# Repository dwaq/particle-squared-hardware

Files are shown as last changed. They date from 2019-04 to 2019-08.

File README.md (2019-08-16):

# Particle Squared - Bare Bones

This is a forked version of [Jared Wolff's Particle Squared Hardware](https://bitbucket.org/circuitdojo/particle-squared-hardware). For more information on that board, [visit his website](https://www.jaredwolff.com/particle-squared-air-quality-sensor/). To support him and his work, you can  [order his sensors from here](https://www.jaredwolff.com/store/particle-squared/).

Particle^2 (pronounced Particle Squared) is a circuit board that helps you monitor the air quality around you. I call my fork of the project "Bare Bones" because I removed the air particulate sensor. It can still monitor humidity, temperature, eCO2 and TVOCs.

I also made some minor changes to the project to suit my goals.

This project was designed using Autodesk Eagle.

The [Eagle-Renders](/Eagle-Renders) directory contains PDF and PNG renders of the schematic and board layout.

[Here is a shared project on Mouser for the BOM for one PCB.](https://www.mouser.com/ProjectManager/ProjectDetail.aspx?AccessID=5dd38de383)

## License

The license for these files is: [Attribution-ShareAlike 4.0 International](https://creativecommons.org/licenses/by-sa/4.0/). See included `LICENSE` file for all the legal stuff.

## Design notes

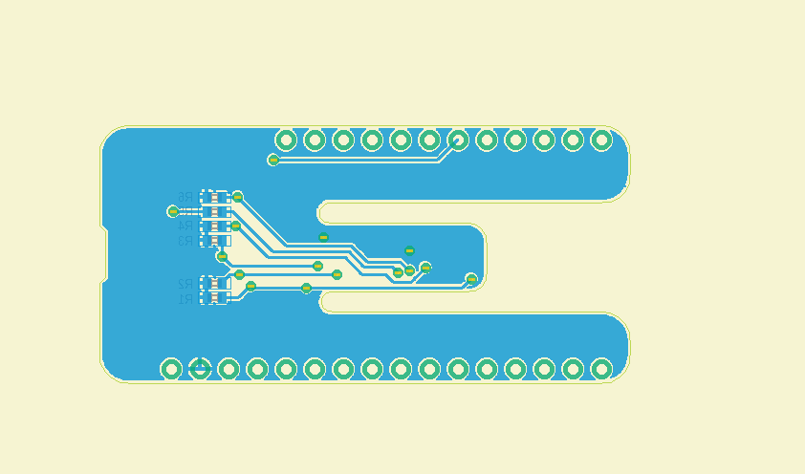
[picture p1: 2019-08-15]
Eagle-Renders/pm25.bot.brd.png

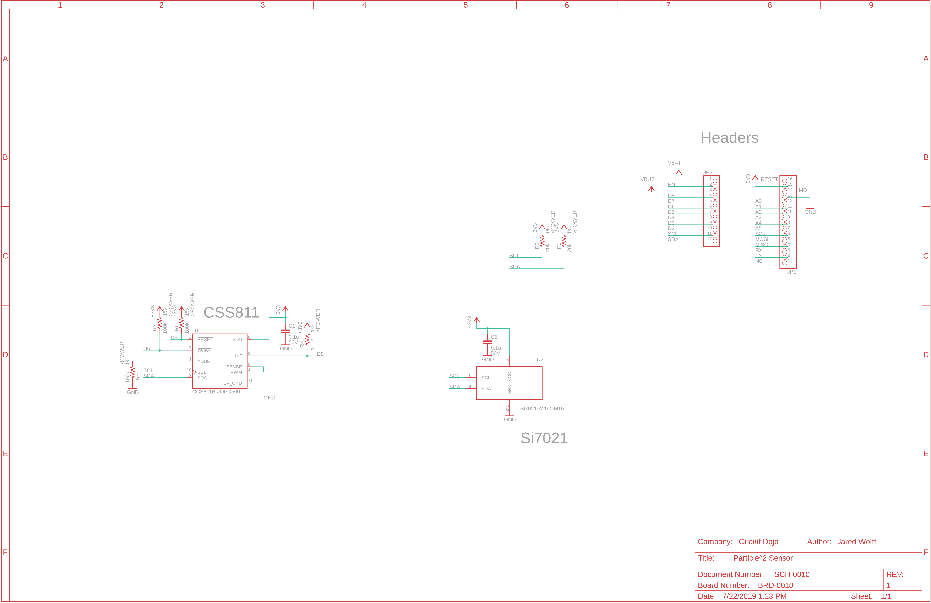
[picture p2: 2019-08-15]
Eagle-Renders/pm25.sch.png

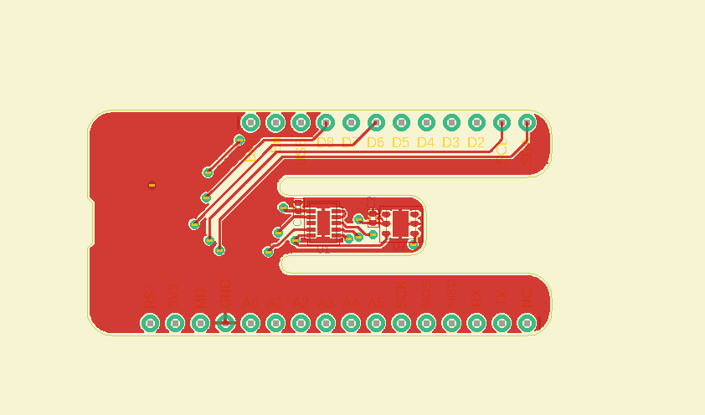
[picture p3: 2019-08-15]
Eagle-Renders/pm25.top.brd.png

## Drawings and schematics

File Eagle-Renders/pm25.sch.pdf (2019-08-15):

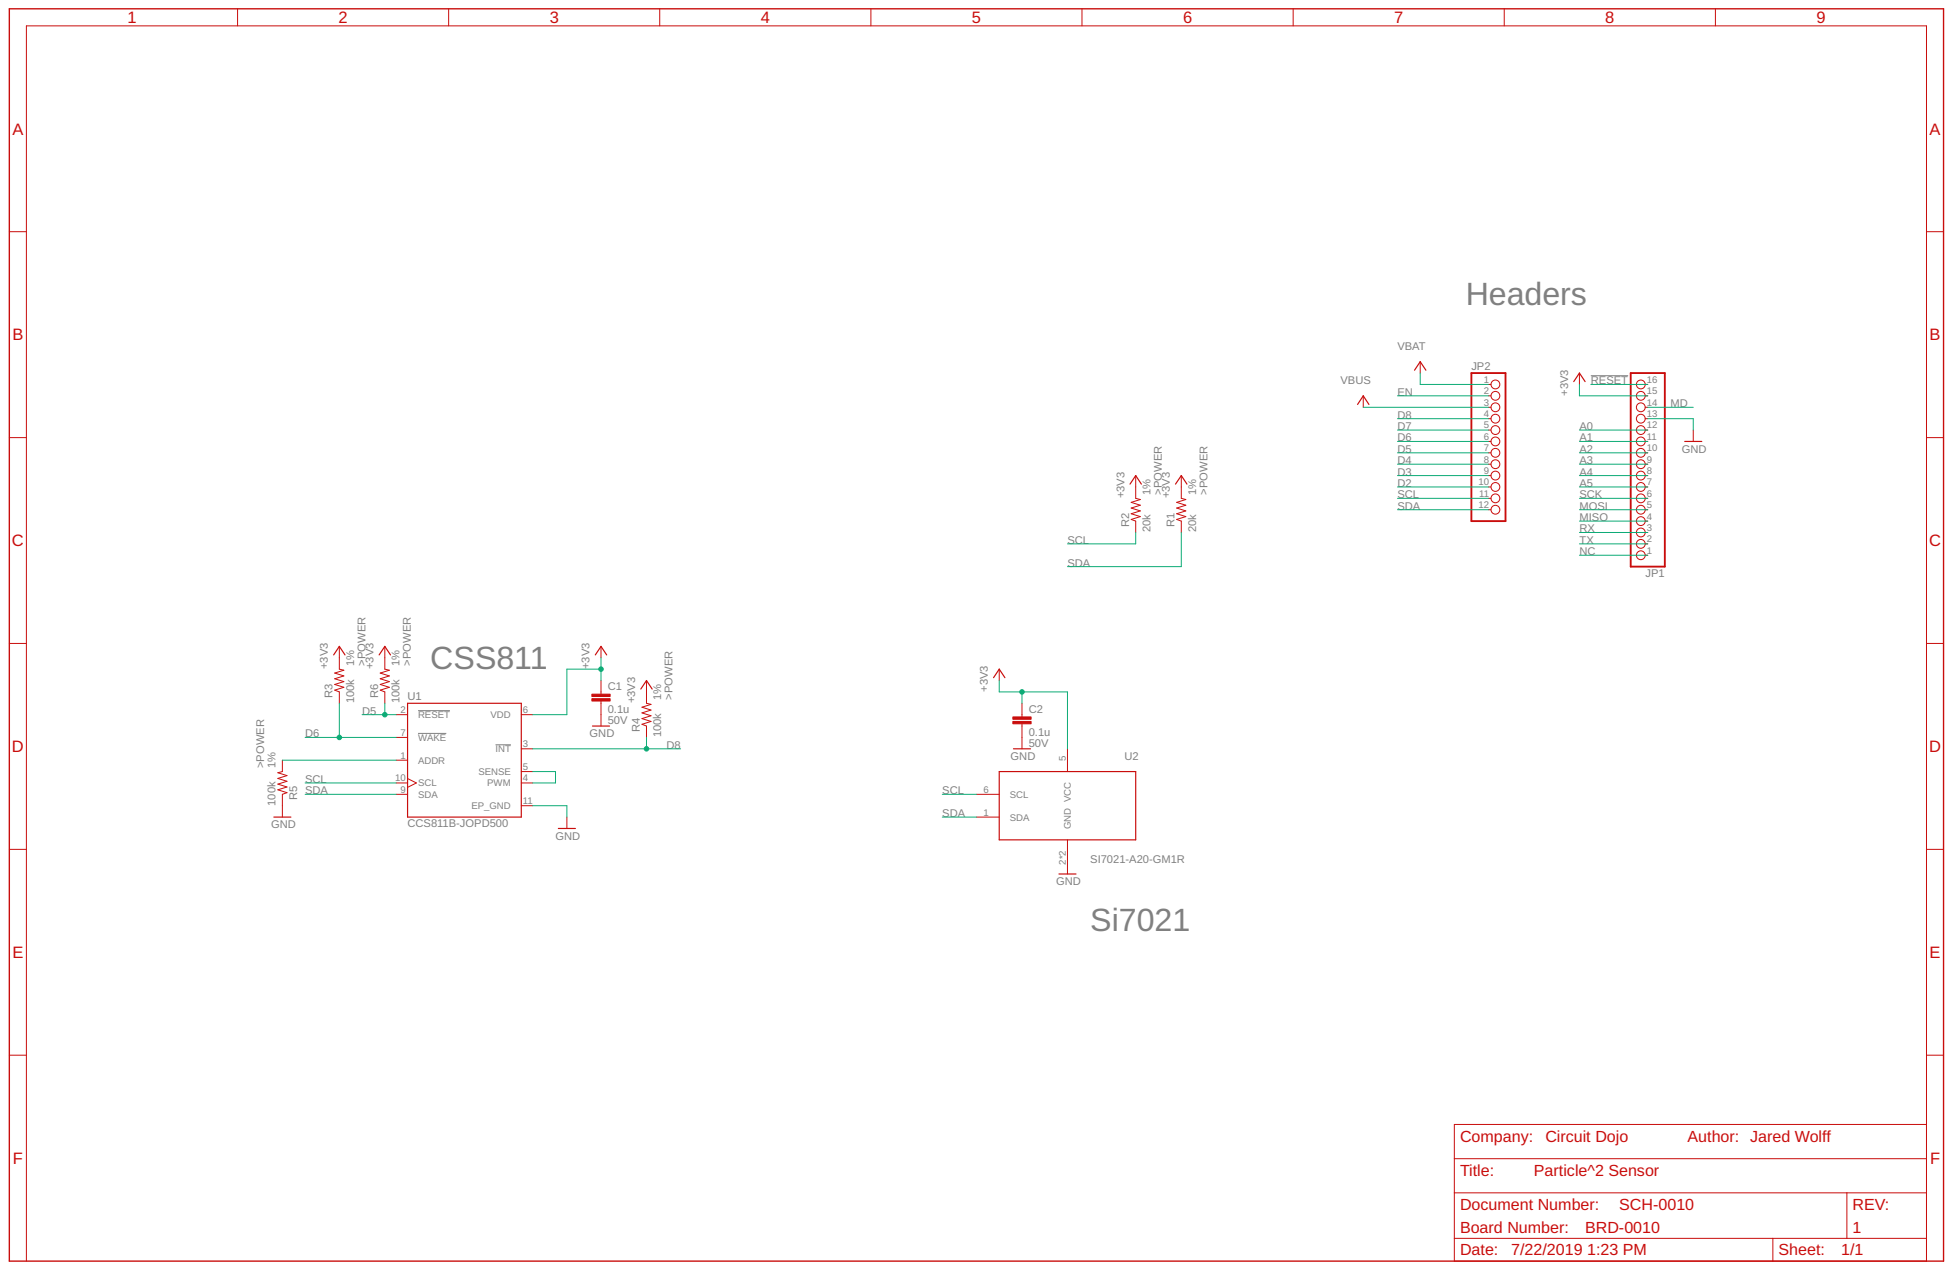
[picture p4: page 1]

Document Number: SCH-0010 Board Number: BRD-0010 | REV: 1

Date: 7/22/2019 1:23 PM | Sheet: 1/1

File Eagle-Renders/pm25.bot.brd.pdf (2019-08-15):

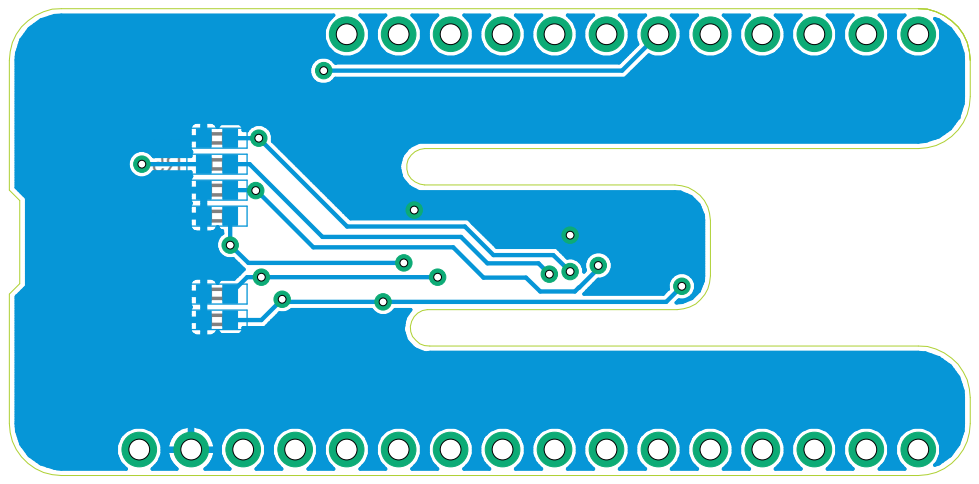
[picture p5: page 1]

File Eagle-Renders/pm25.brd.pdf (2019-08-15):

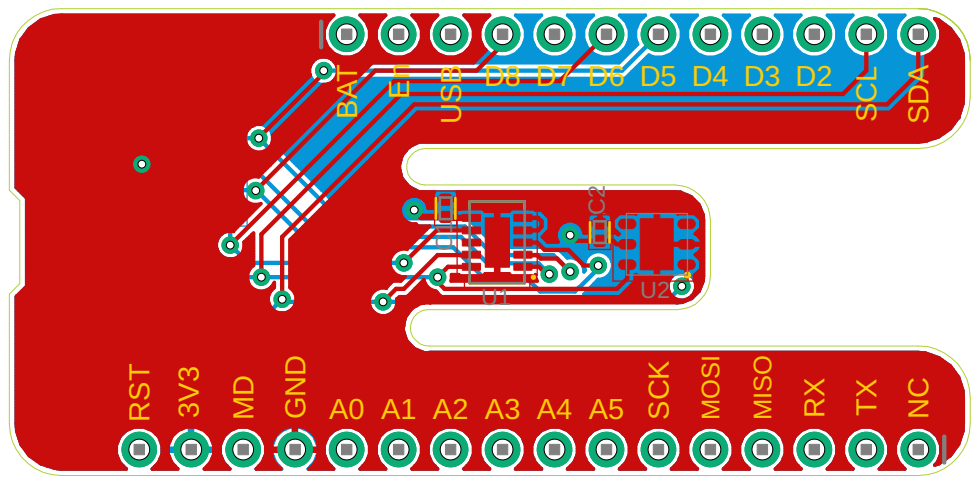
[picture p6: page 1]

6 R3 R4 R5 R2 R1 R USB SCL SDA BATEn RST MD3V3 A0 A1 A2 A3 A4 A5 SCK MOSI MISO RXTXGND NC D8 D7 D6 D5 D4 D3 D2 U1 U2 C1 C2

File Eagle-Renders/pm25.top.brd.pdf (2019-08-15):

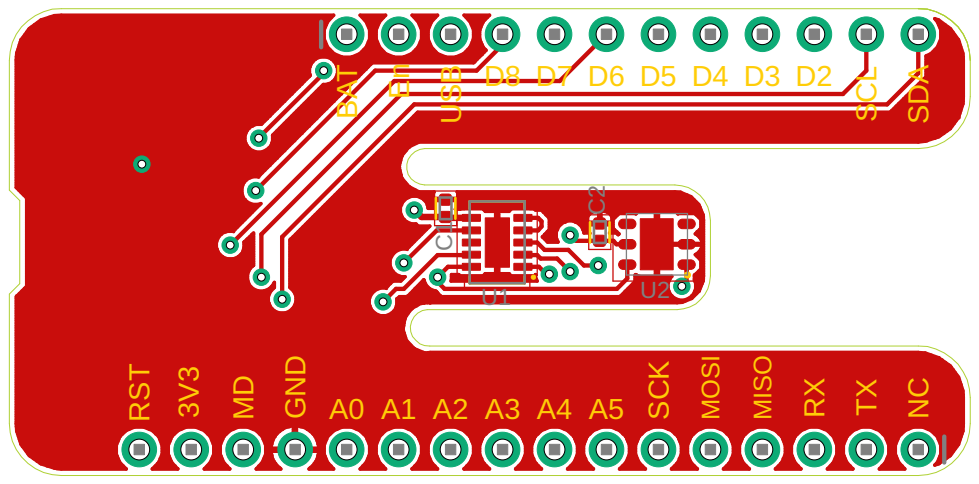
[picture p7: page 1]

3V3 A0 A1 A2 A3 A4 A5 SCK MOSI MISO RX

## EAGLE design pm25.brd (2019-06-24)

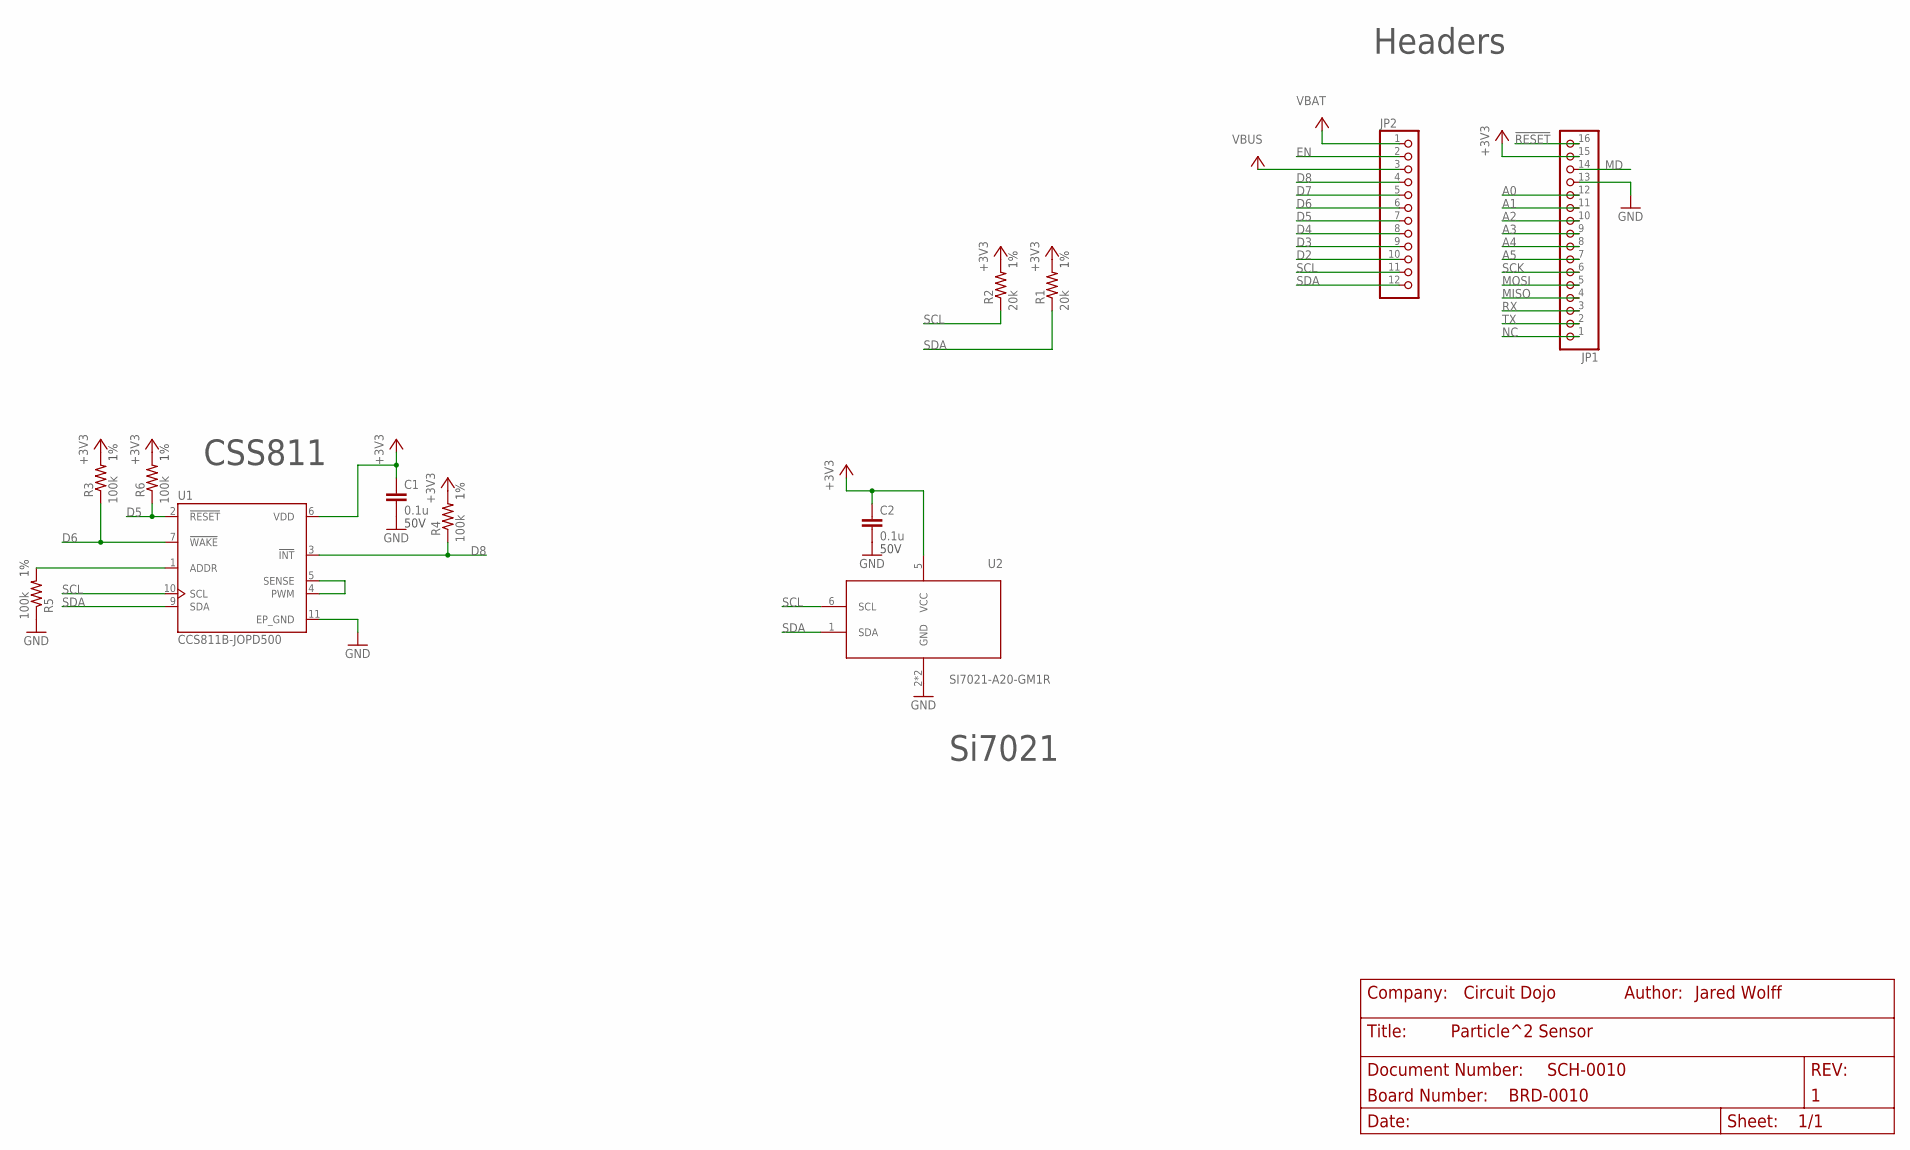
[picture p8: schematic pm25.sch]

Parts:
C1, C2: 0.1u; CAPC1005X55N
JP1: HEADER-1X16ROUND; 1X16_ROUND; MPN PPPC161LFBN-RC
JP2: HEADER-1X12; 1X12_ROUND; MPN PPPC121LFBN-RC
R1, R2: 20k; R0402
R3, R4, R5, R6: 100k; R0402
U1: CCS811B-JOPD500; SON60P400X270X110-11N
U2: SI7021-A20-GM1R; SON100P300X300X80-7N

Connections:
!RESET: JP1.16
+3V3: C1.1, C2.1, JP1.15, R1.2, R2.2, R3.2, R4.2, R6.2, U1.6 (VDD), U2.5 (VCC)
A0: JP1.12
A1: JP1.11
A2: JP1.10
A3: JP1.9
A4: JP1.8
A5: JP1.7
D2: JP2.10
D3: JP2.9
D4: JP2.8
D5: JP2.7, R6.1, U1.2 (!RESET)
D6: JP2.6, R3.1, U1.7 (!WAKE)
D7: JP2.5
D8: JP2.4, R4.1, U1.3 (!INT)
EN: JP2.2
GND: C1.2, C2.2, JP1.13, R5.1, U1.11 (EP_GND), U2.2 (GND), U2.7 (GND)
MD: JP1.14
MISO: JP1.4
MOSI: JP1.5
unnamed: R5.2, U1.1 (ADDR)
unnamed: U1.4 (PWM), U1.5 (SENSE)
NC: JP1.1
RX: JP1.3
SCK: JP1.6
SCL: JP2.11, R2.1, U1.10 (SCL), U2.6 (SCL)
SDA: JP2.12, R1.1, U1.9 (SDA), U2.1 (SDA)
TX: JP1.2
VBAT: JP2.1
VBUS: JP2.3

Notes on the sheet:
Si7021
CSS811
Headers

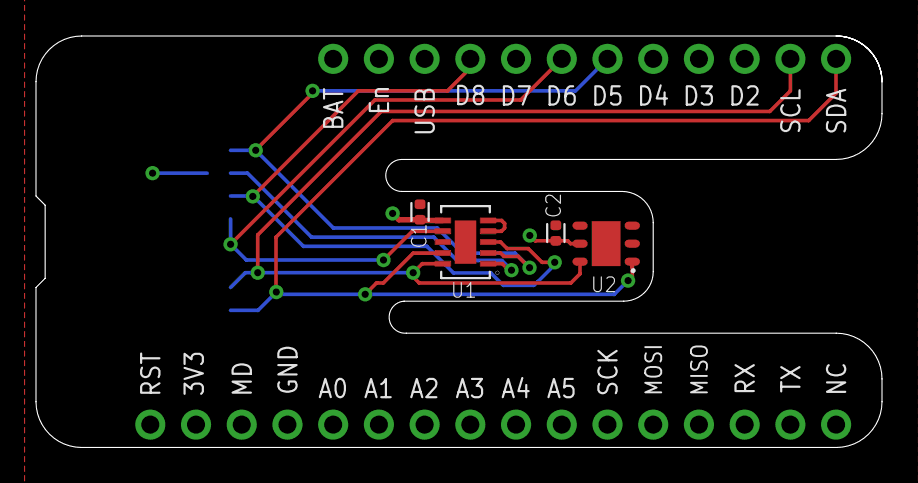
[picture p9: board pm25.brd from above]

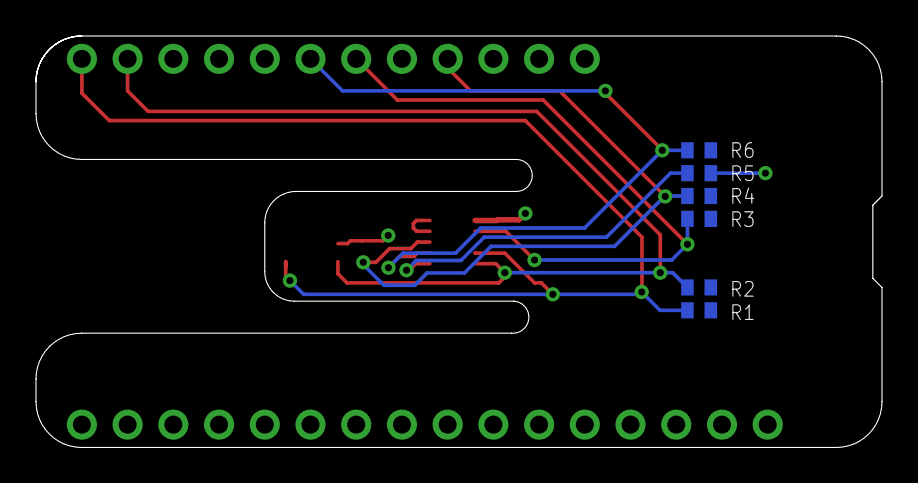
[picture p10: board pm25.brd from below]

Board: 2 copper layers, 47.0 x 22.9 mm, 12 parts (6 on the bottom side), 9 nets.

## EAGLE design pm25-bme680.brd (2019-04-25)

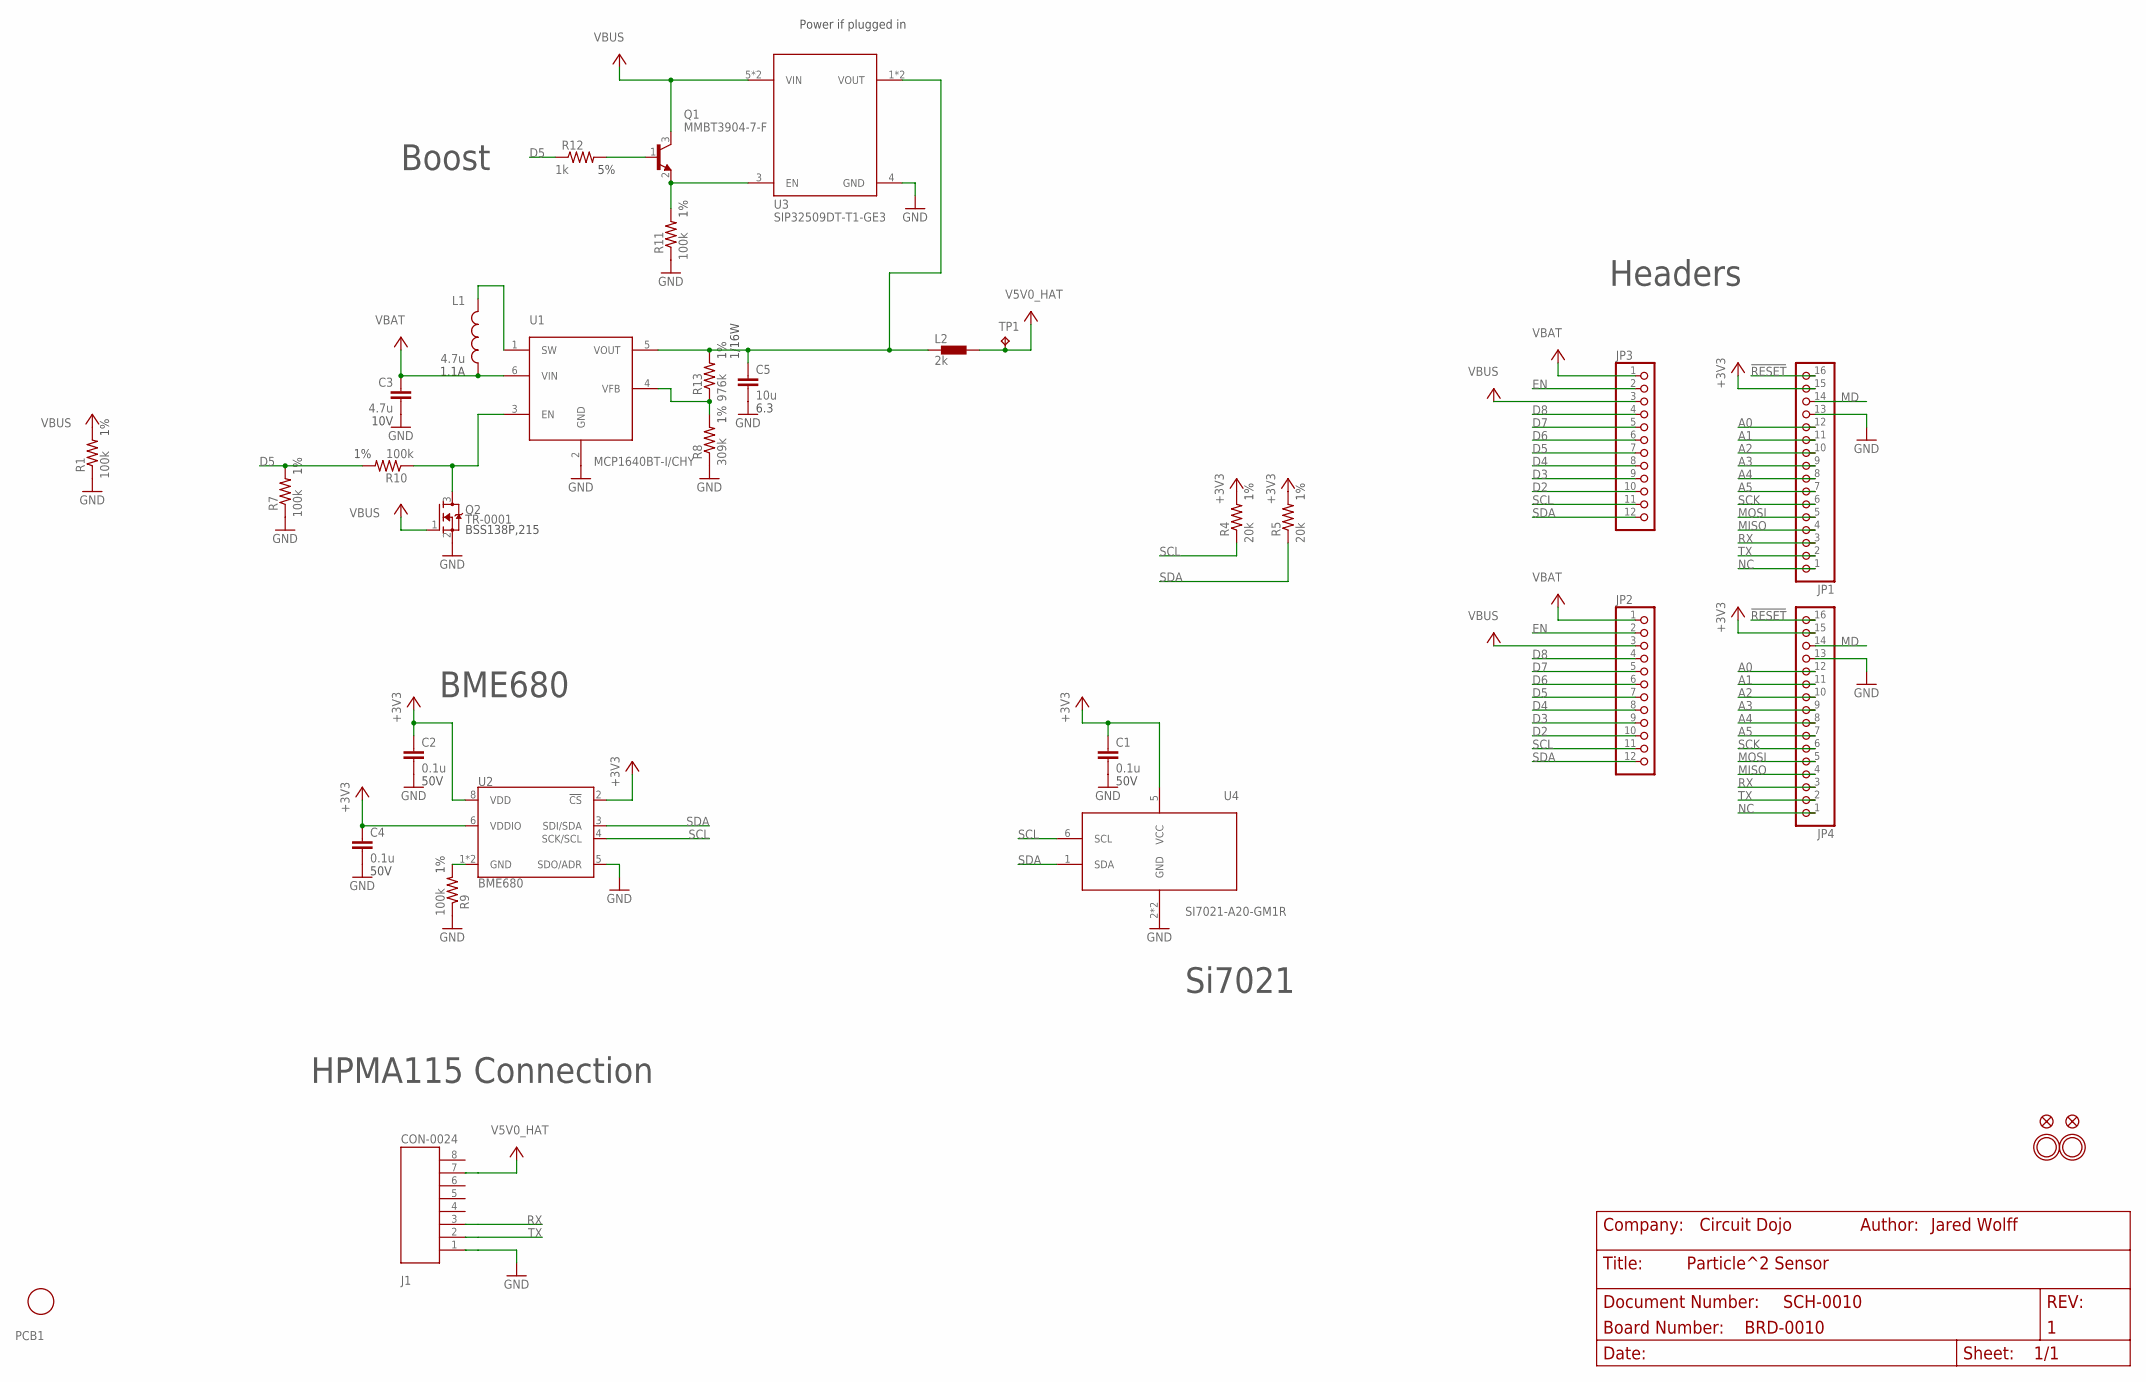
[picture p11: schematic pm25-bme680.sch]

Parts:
C1, C2, C4: 0.1u; CAPC1005X55N
C3: 4.7u; C0603
C5: 10u; C0603
J1: CON-0024; 0532610871
JP1: HEADER-1X16ROUND; 1X16_ROUND; MPN PPPC161LFBN-RC
JP2: HEADER-1X12; 1X12_ROUND
JP3: HEADER-1X12; 1X12_ROUND; MPN PPPC121LFBN-RC
JP4: HEADER-1X16ROUND; 1X16_ROUND
L1: 4.7u; IND-2P0X2P0X1P2
L2: 2k; R0805
PCB1: PCB-BME680-SI7021; PLACEHOLDER
Q1: TRANSISTOR-NPN-40V-0.2A-SOT23; SOT23
Q2: TR-0001; SOT23
R1, R7, R9, R10, R11: 100k; R0402
R4, R5: 20k; R0402
R8: 309k; R0402
R12: 1k; R0402
R13: 976k; R0402
TP1: TP; TP-1P27
U1: POWER-VREG-FB-EN-SW-350MA; SOT23-6
U2: BME680; LGA3.0X3.0
U3: POWER-SWITCH-SIP32509DT; SOT23-6
U4: SI7021-A20-GM1R; SON100P300X300X80-7N
U$31, U$32: MOUNTINGHOLE2.5; MOUNTINGHOLE_2.5_PLATED
U$34, U$35: FIDUCIAL""; FIDUCIAL_1MM

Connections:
!RESET: JP1.16, JP4.16
+3V3: C1.1, C2.1, C4.1, JP1.15, JP4.15, R4.2, R5.2, U2.2 (!CS), U2.6 (VDDIO), U2.8 (VDD), U4.5 (VCC)
A0: JP1.12, JP4.12
A1: JP1.11, JP4.11
A2: JP1.10, JP4.10
A3: JP1.9, JP4.9
A4: JP1.8, JP4.8
A5: JP1.7, JP4.7
D2: JP2.10, JP3.10
D3: JP2.9, JP3.9
D4: JP2.8, JP3.8
D5: JP2.7, JP3.7, R7.2, R10.2, R12.1
D6: JP2.6, JP3.6
D7: JP2.5, JP3.5
D8: JP2.4, JP3.4
EN: JP2.2, JP3.2
GND: C1.2, C2.2, C3.2, C4.2, C5.2, J1.1, JP1.13, JP4.13, Q2.2 (S), R1.1, R7.1, R8.1, R9.1, R11.1, U1.2 (GND), U2.5 (SDO/ADR), U3.4 (GND), U4.2 (GND), U4.7 (GND)
MD: JP1.14, JP4.14
MISO: JP1.4, JP4.4
MOSI: JP1.5, JP4.5
unnamed: L1.P$1 (1), U1.1 (SW)
unnamed: R8.2, R13.1, U1.4 (VFB)
unnamed: Q1.2 (E), R11.2, U3.3 (EN)
unnamed: R9.2, U2.1 (GND), U2.7 (GND)
unnamed: Q2.3 (D), R10.1, U1.3 (EN)
unnamed: Q1.1 (B), R12.2
NC: JP1.1, JP4.1
RX: J1.3, JP1.3, JP4.3
SCK: JP1.6, JP4.6
SCL: JP2.11, JP3.11, R4.1, U2.4 (SCK/SCL), U4.6 (SCL)
SDA: JP2.12, JP3.12, R5.1, U2.3 (SDI/SDA), U4.1 (SDA)
TX: J1.2, JP1.2, JP4.2
V5V0_BEAD: C5.1, L2.1, R13.2, U1.5 (VOUT), U3.1 (VOUT), U3.2 (VOUT)
V5V0_HAT: J1.7, L2.2, TP1.P$1, TP1.P$2, TP1.TP
VBAT: C3.1, JP2.1, JP3.1, L1.P$2 (2), U1.6 (VIN)
VBUS: JP2.3, JP3.3, Q1.3 (C), Q2.1 (G), R1.2, U3.5 (VIN), U3.6 (VIN)

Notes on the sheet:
Boost
Si7021
BME680
HPMA115 Connection
Headers
Power if plugged in

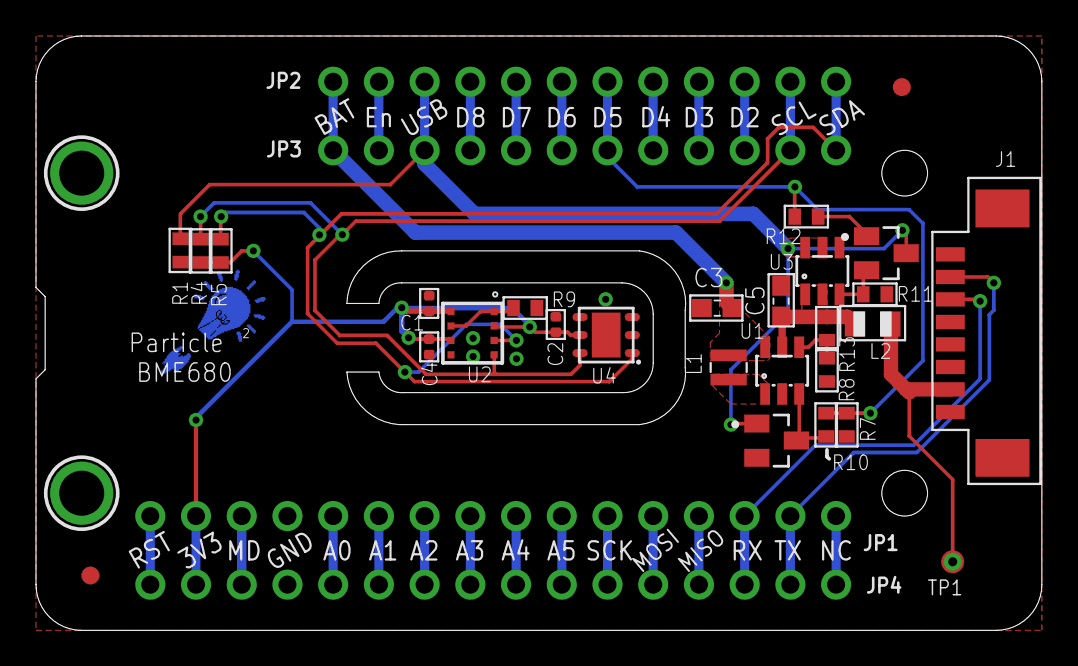
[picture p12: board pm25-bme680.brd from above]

Board: 2 copper layers, 55.9 x 33.0 mm, 34 parts (0 on the bottom side), 36 nets.

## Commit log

2019-04-25 First commit. BME680 version.
    [pm25-bme680.brd, pm25-bme680.sch]
2019-06-20 remove dust sensor and other extra circuitry
    [pm25.brd, pm25.sch]
2019-06-21 made a cut out that extends to a smaller board size
    [pm25.brd]
2019-06-21 finally deleted those holes
    [pm25.brd]
2019-06-24 Shrink width to 0.9" standard
    [pm25.brd]
2019-06-24 roundover the central cutout
    [pm25.brd]
2019-06-24 Move pin label silkscreen from bottom to top
    [pm25.brd]
2019-06-24 Un-mirror text now that its on the top
    [pm25.brd]
2019-06-24 deleted one last piece of silkscreen
    [pm25.brd]
2019-06-24 rip up all traces outside of island
    [pm25.brd]
2019-06-24 Move resistors to bottom and align
    [pm25.brd]
2019-06-24 Huge reroute effort - not done yet
    Also replace pours: Top=GND, Bottom=+3V3
    [pm25.brd]
2019-06-24 Opened up the channel and improved the routing
    [pm25.brd]
2019-06-24 routing done but pours barely connect
    [pm25.brd]
2019-06-24 happy with the routing now
    [pm25.brd]
2019-06-24 rename the parts sequentially
    [pm25.brd, pm25.sch]
2019-06-24 Move some silkscreen around
    [pm25.brd]
2019-06-24 remove logo from silkscreen
    [pm25.brd]
2019-06-24 more minor silkscreen changes
    [pm25.brd]
2019-06-24 line up all the pin names on silkscreen
    [pm25.brd]
2019-06-24 Gerbers for PCB ordered
2019-08-15 Remove outdated fritzing diagram
    [particle-squared.fzz]
2019-08-15 Export schematic as PDF and PNG (300dpi)
2019-08-15 Export board (standard/top/bottom) as PNG (300dpi)
2019-08-15 Export board (standard/top/bottom) as PDF
2019-08-15 Use Eagle's print to file function for schematic
2019-08-16 add link to Mouser BOM

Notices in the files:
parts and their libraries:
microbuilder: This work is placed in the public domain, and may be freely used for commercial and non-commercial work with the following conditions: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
